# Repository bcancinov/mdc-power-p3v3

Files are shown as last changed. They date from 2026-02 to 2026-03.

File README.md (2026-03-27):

# mdc-power-p3v3
Modular Detector Controller Power 3.3V DC-DC Mezzanine Module

## Overview
12V input to 3.3V output DC-DC module, 8A nominal output, used as one of the `mdc-power-*` bias rails.
Designed for 2 MHz sync operation.
Mezzanine module.

## Power Stage
- Controller: `LT8627SP` (`U1`)
  - Silent Switcher 3 synchronous step-down regulator.
  - Ultralow EMI emissions and high efficiency at high switching frequency.
  - Constant-frequency current-mode control.
  - External sync capability.
- Inductor: `L1` = `1uH`
  - Uses the XGL5030 shielded power inductor family (see `docs/xgl5030.pdf`).
  - Shielded construction to reduce radiated EMI and coupling into sensitive nodes.
  - Very low DCR family to reduce copper loss and improve efficiency.
  - Low AC loss construction optimized for high-frequency switching.

## Files
- Schematic: `power_p3v3.pdf`
- Simulation: `sim/` (LTspice and LTpowerCAD files used for loop and transient checks)

## Board Dimensions
- 44.8 mm x 41.5 mm

## Board Stackup
- 4-layer PCB

## CAD
- Designed using KiCad 9.

## Interface
- Control pins: `EN` (enable) and `PG` / `~PGOOD` (power good).
- Connector: `LSHM-140-04.0-L-DV-A-N-K-TR` (Samtec LSHM series) mezzanine for power and control signals.
  - Common pinout is shared across the 16V, -16V, 6V, and 3.3V variants.
  - Unused output rails are tied to GND on the specific module variant.

## Images
Layout:
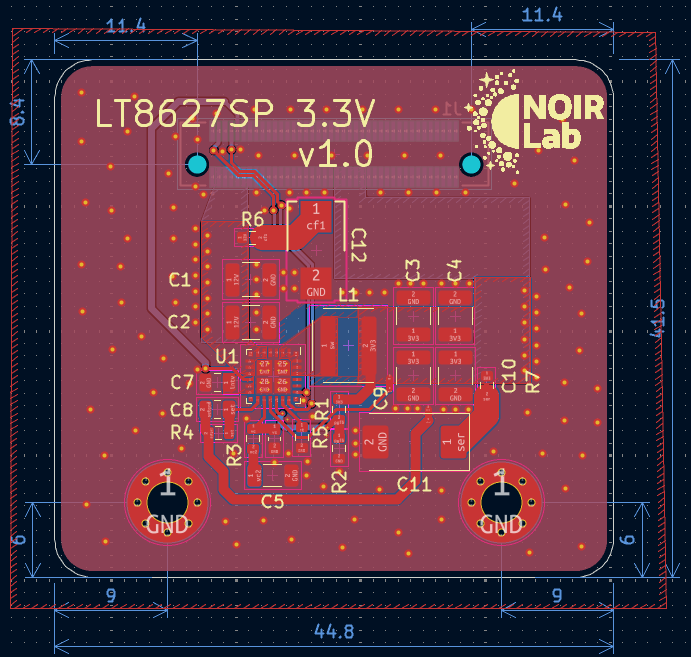
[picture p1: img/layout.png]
Layout


3D view:
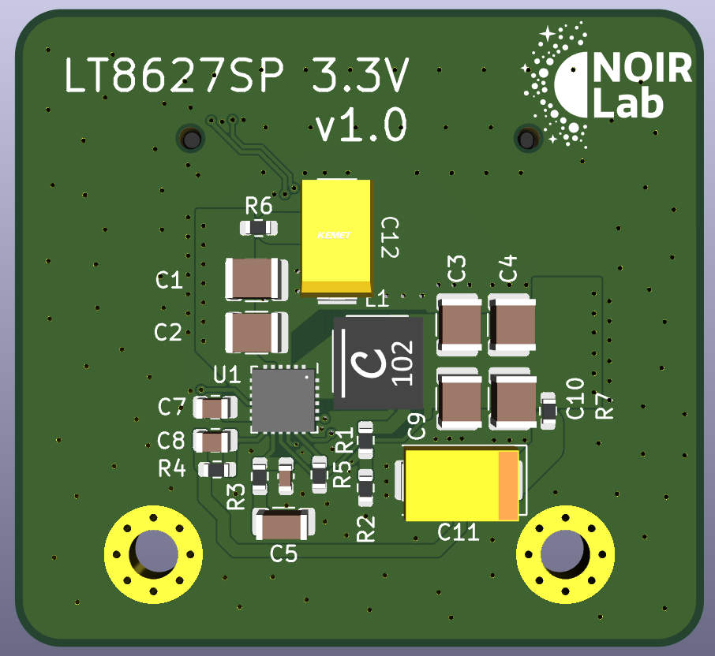
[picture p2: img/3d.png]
3D view


## License

This hardware design is licensed under the **Creative Commons Attribution-NonCommercial-ShareAlike 4.0 International License** (CC BY-NC-SA 4.0).

You are free to download, modify, and build upon this design for your own research or personal use, provided you give appropriate credit and share your modifications under the exact same license. **Commercial manufacturing or use of these designs is strictly prohibited without explicit permission.**

To view a copy of this license, visit [http://creativecommons.org/licenses/by-nc-sa/4.0/](http://creativecommons.org/licenses/by-nc-sa/4.0/) or see the `LICENSE` file in this repository.

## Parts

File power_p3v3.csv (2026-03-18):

Reference | Qty | MPN | M | Description
C1,C2 | 2 | GCM32ER71H475KA55K | Murata | 4.7 µF ±10% 50V Ceramic Capacitor X7R 1210 (3225 Metric)
C3,C4,C9,C10 | 4 | TMK325ABJ476MM-P | TAIYO YUDEN | 47 µF ±20% 25V Ceramic Capacitor X5R 1210 (3225 Metric)
C5 | 1 | GCM31C5C1H104FA16L | Murata | 0.1 µF ±1% 50V Ceramic Capacitor C0G, NP0 1206 (3216 Metric)
C6 | 1 | GCM1885C2A270FA16D | Murata | 27 pF ±1% 100V Ceramic Capacitor C0G, NP0 0603 (1608 Metric)
C7,C8 | 2 | GCM21BR71H105KA03L | Murata | 1 µF ±10% 50V Ceramic Capacitor X7R 0805 (2012 Metric)
C11 | 1 | T521V226M025ATE040 | KEMET | 22 µF Molded Tantalum Polymer Capacitor 25 V 2917 (7343 Metric) 40mOhm @ 100kHz
C12 | 1 | T521X107M025ATE060 | Kemet | 100 µF Molded Tantalum Polymer Capacitor 25 V 2917 (7343 Metric) 60mOhm @ 100kHz
H1,H2,NT1,NT2 | 4 |  |  | Mounting Hole with connection,Net tie, 2 pins
J1 | 1 | LSHM-140-04.0-L-DV-A-N-K-TR | Samtec | 80 Position Connector Self Mating, Non-Gendered, Hermaphroditic Surface Mount Gold
L1 | 1 | XGL5030-102MEC | Coilcraft | 1 µH Shielded Molded Inductor 17.8 A 5.8mOhm Max Nonstandard
R1 | 1 | CRCW060310K0FKEA | Vishay | 10 kOhms ±1% 0.125W, 1/8W Chip Resistor 0603 (1608 Metric) Automotive AEC-Q200 Thick Film
R2 | 1 | CRCW06031K78FKEA | Vishay | 1.78 kOhms ±1% 0.125W, 1/8W Chip Resistor 0603 (1608 Metric) Automotive AEC-Q200 Thick Film
R3 | 1 | CRCW06031K00FKEA | Vishay | 1 kOhms ±1% 0.125W, 1/8W Chip Resistor 0603 (1608 Metric) Automotive AEC-Q200 Thick Film
R4 | 1 | ERA-3AEB333V | Panasonic | 33 kOhms ±0.1% 0.1W, 1/10W Chip Resistor 0603 (1608 Metric) Automotive AEC-Q200 Thin Film
R5 | 1 | CRCW060347K5FKEA | Vishay | 47.5 kOhms ±1% 0.125W, 1/8W Chip Resistor 0603 (1608 Metric) Automotive AEC-Q200 Thick Film
R6,R7 | 2 | RCWE0603R500FKEA | Vishay | 500 mOhms ±1% 0.2W, 1/5W Chip Resistor 0603 (1608 Metric) Automotive AEC-Q200, Current Sense, Moisture Resistant Thick Film
U1 | 1 | LT8627SPJV#TRPBF | Analog | Buck Switching Regulator IC Positive Adjustable 1 Output 16A 24-TFQFN Exposed Pad

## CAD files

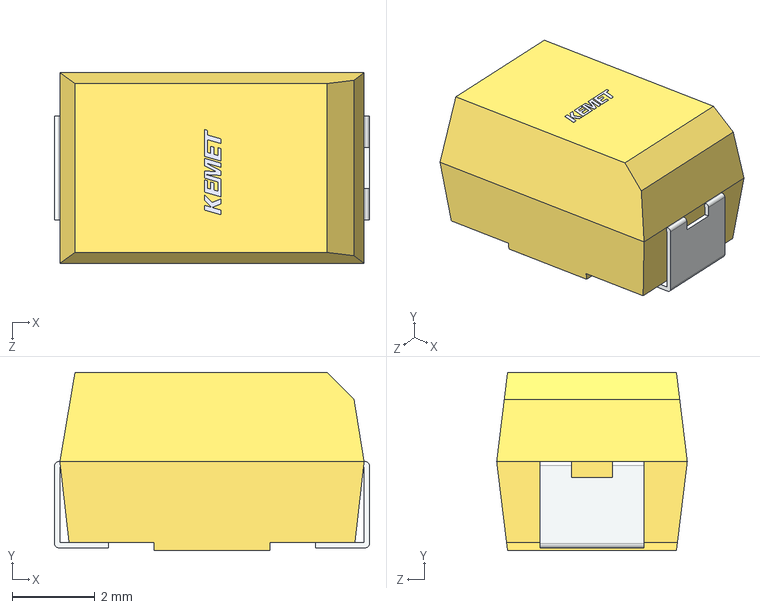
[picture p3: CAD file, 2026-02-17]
step/T521X.step
7.60 x 4.30 x 4.60 mm

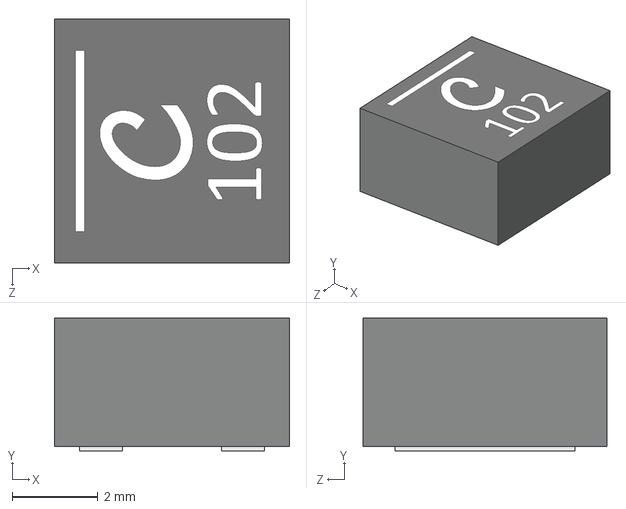
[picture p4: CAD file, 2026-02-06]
step/Coilcraft-XGL5030-102.step
5.48 x 3.10 x 5.68 mm

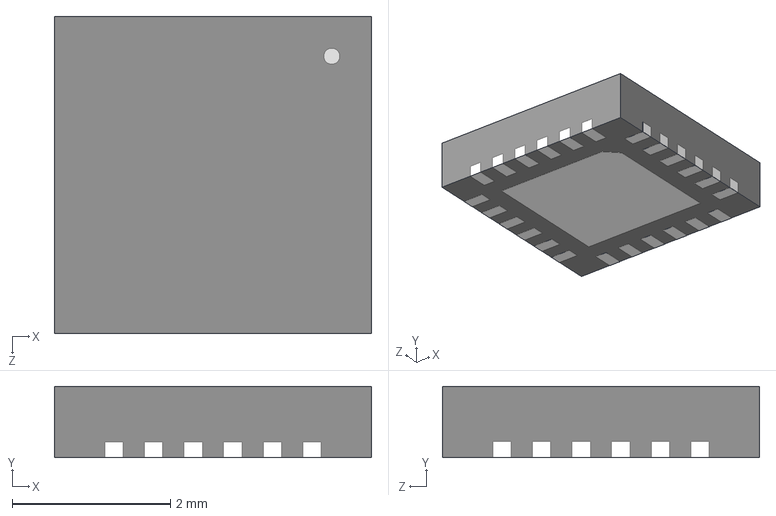
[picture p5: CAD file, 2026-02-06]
step/QFN 24 4x4.step
4.00 x 0.9 x 4.00 mm

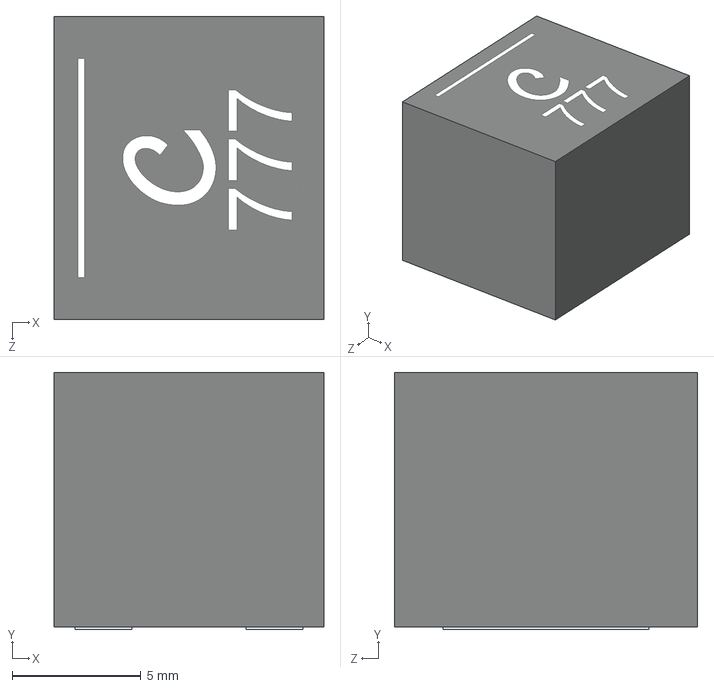
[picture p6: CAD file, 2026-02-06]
step/Coilcraft-XGL1010.step
10.5 x 10.0 x 11.8 mm

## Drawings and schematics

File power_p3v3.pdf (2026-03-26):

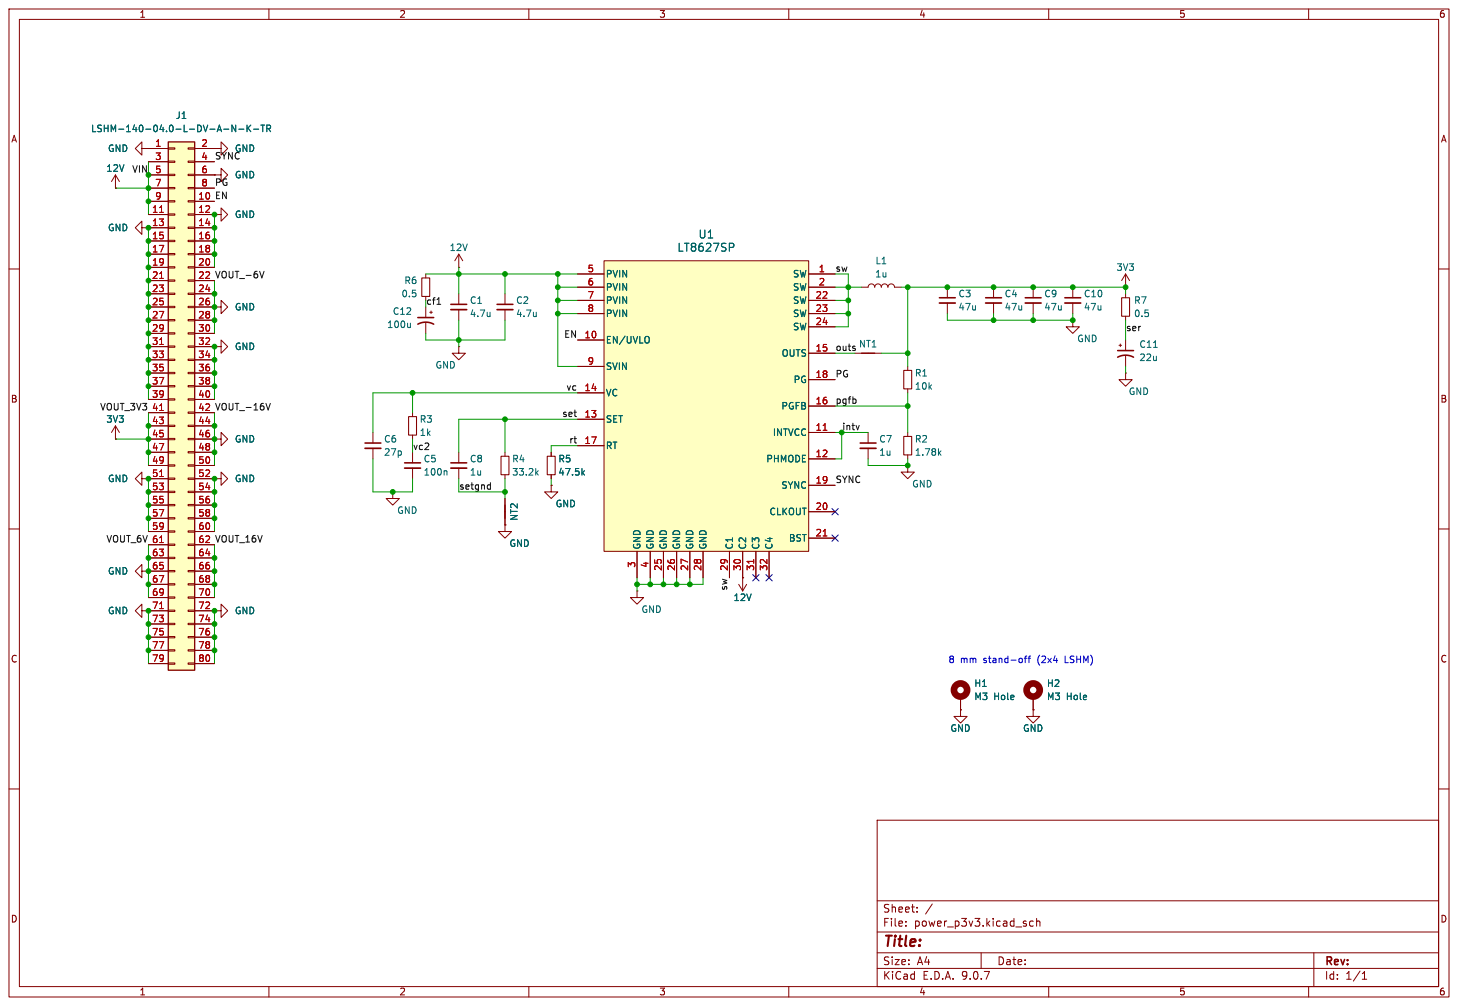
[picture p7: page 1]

4 GND 25 GND 26 GND 27 GND 28 C1 29 C2 30 C3 31 C4 32 SW 1 SW 2 SW 22 SW 23 SW 24 OUTS 15 PG 18 PGFB 16

intv outs pgfb PG

Id: 1/1 Title: File: power_p3v3.kicad_sch Sheet: /

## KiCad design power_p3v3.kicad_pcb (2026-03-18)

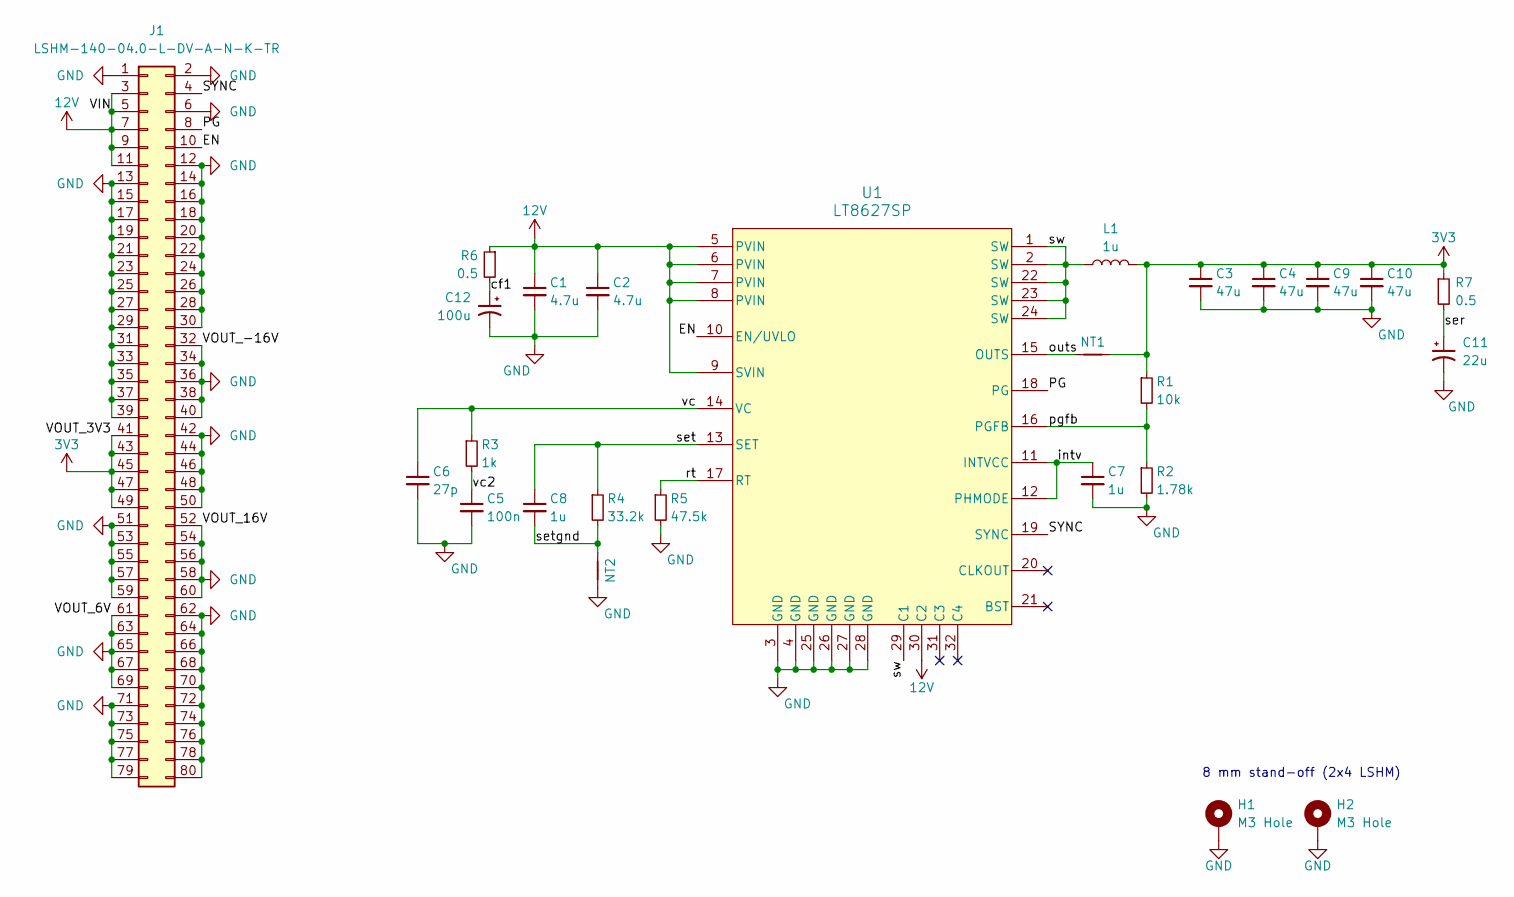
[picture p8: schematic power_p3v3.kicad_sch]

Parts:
C1, C2: 4.7u; C_1210_3225Metric; MPN GCM32ER71H475KA55K
C3, C4, C9, C10: 47u; C_1210_3225Metric; MPN TMK325ABJ476MM-P
C5: 100n; C_1206_3216Metric; MPN GCM31C5C1H104FA16L
C6: 27p; C_0603_1608Metric; MPN GCM1885C2A270FA16D
C7, C8: 1u; C_0805_2012Metric; MPN GCM21BR71H105KA03L
C11: 22u; CP_EIA-7343-20_Kemet-V; MPN T521V226M025ATE040
C12: 100u; T521X; MPN T521X107M025ATE060
H1, H2: M3 Hole; MountingHole_3.2mm_M3_Pad_Via
J1: LSHM-140-04.0-L-DV-A-N-K-TR; SAMTEC_LSHM-140-04.0-L-DV-A-N-K-TR; MPN LSHM-140-04.0-L-DV-A-N-K-TR
L1: 1u; XGL5030; MPN XGL5030-102MEC
NT1, NT2: NetTie_2; NetTie-2_SMD_Pad0.5mm
R1: 10k; R_0603_1608Metric; MPN CRCW060310K0FKEA
R2: 1.78k; R_0603_1608Metric; MPN CRCW06031K78FKEA
R3: 1k; R_0603_1608Metric; MPN CRCW06031K00FKEA
R4: 33.2k; R_0603_1608Metric; MPN ERA-3AEB333V
R5: 47.5k; R_0603_1608Metric; MPN CRCW060347K5FKEA
R6, R7: 0.5; R_0603_1608Metric; MPN RCWE0603R500FKEA
U1: LT8627SP; QFN-24_EP_4x4_Pitch0.5mm; MPN LT8627SPJV#TRPBF

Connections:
3V3: C3.1, C4.1, C9.1, C10.1, J1.41, J1.43, J1.45, J1.47, J1.49, L1.2, NT1.2, R1.1, R7.1
12V: C1.1, C2.1, J1.3, J1.5, J1.7, J1.9, J1.11, R6.1, U1.5 (PVIN), U1.6 (PVIN), U1.7 (PVIN), U1.8 (PVIN), U1.9 (SVIN), U1.30 (C2)
/EN: J1.10, U1.10 (EN/UVLO)
/PG: J1.8, U1.18 (PG)
/SYNC: J1.4, U1.19 (SYNC)
/cf1: C12.1, R6.2
/intv: C7.1, U1.11 (INTVCC), U1.12 (PHMODE)
/outs: NT1.1, U1.15 (OUTS)
/pgfb: R1.2, R2.1, U1.16 (PGFB)
/rt: R5.1, U1.17 (RT)
/ser: C11.1, R7.2
/set: C8.1, R4.1, U1.13 (SET)
/setgnd: C8.2, NT2.1, R4.2
/sw: L1.1, U1.1 (SW), U1.2 (SW), U1.22 (SW), U1.23 (SW), U1.24 (SW), U1.29 (C1)
/vc: C6.1, R3.1, U1.14 (VC)
/vc2: C5.1, R3.2
GND: C1.2, C2.2, C3.2, C4.2, C5.2, C6.2, C7.2, C9.2, C10.2, C11.2, C12.2, H1.1, H2.1, J1.1, J1.2, J1.6, J1.12, J1.13, J1.14, J1.15, J1.16, J1.17, J1.18, J1.19, J1.20, J1.21, J1.22, J1.23, J1.24, J1.25, J1.26, J1.27, J1.28, J1.29, J1.30, J1.31, J1.32, J1.33, J1.34, J1.35, J1.36, J1.37, J1.38, J1.39, J1.40, J1.42, J1.44, J1.46, J1.48, J1.50, J1.51, J1.52, J1.53, J1.54, J1.55, J1.56, J1.57, J1.58, J1.59, J1.60, J1.61, J1.62, J1.63, J1.64, J1.65, J1.66, J1.67, J1.68, J1.69, J1.70, J1.71, J1.72, J1.73, J1.74, J1.75, J1.76, J1.77, J1.78, J1.79, J1.80, NT2.2, R2.2, R5.2, U1.3 (GND), U1.4 (GND), U1.25 (GND), U1.26 (GND), U1.27 (GND), U1.28 (GND)

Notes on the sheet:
8 mm stand-off (2x4 LSHM)

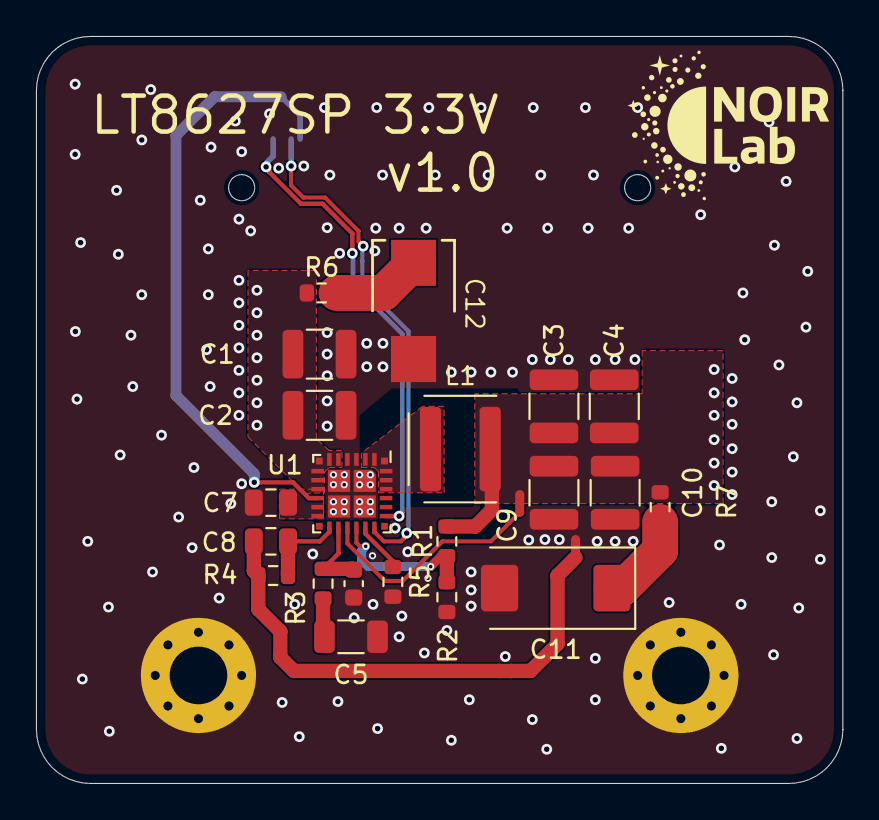
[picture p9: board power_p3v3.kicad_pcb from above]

Board: 4 copper layers, 44.8 x 41.5 mm, 26 parts (1 on the bottom side), 17 nets.

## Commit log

2026-02-06 Add BOM
    [power_p3v3.csv]
2026-02-17 Add Ferrite Beads
    [T521X.step, power_p3v3.csv, power_p3v3.kicad_pcb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]
2026-03-18 update set resistor to thin film
    [power_p3v3.csv, power_p3v3.kicad_pcb, power_p3v3.kicad_sch]
